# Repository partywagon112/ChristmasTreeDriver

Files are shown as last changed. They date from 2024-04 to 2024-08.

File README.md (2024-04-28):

# Christmas Tree Driver
This really should get renamed, but the idea is to create a Matter based H-Bridge driver for my Home Assistant to control my Christmas tree lights at the end of the year.

Very much an in-progress effort...

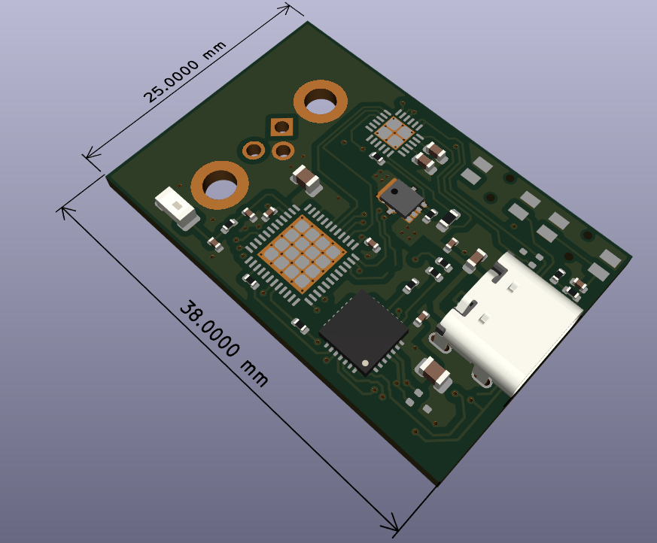
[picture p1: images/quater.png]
ThreeQuaterView


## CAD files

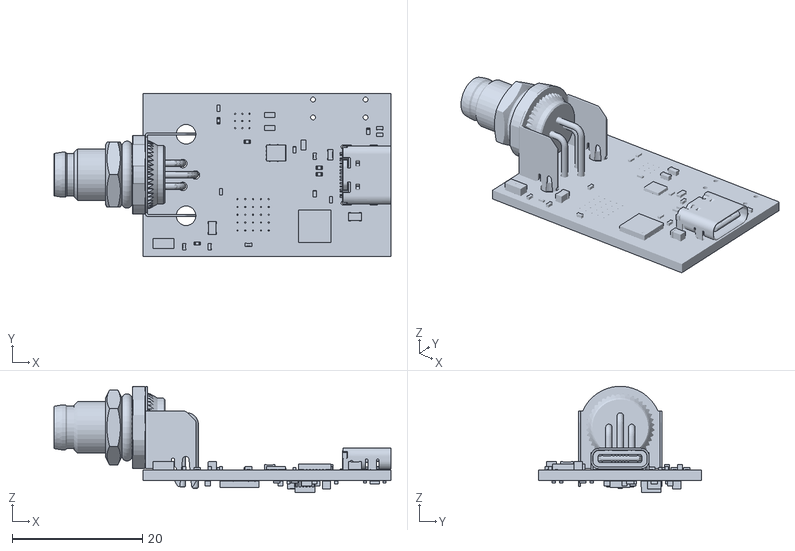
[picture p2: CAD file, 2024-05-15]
hardware/Unnamed-christmastreedriver 1.stl
51.7 x 25.0 x 16.3

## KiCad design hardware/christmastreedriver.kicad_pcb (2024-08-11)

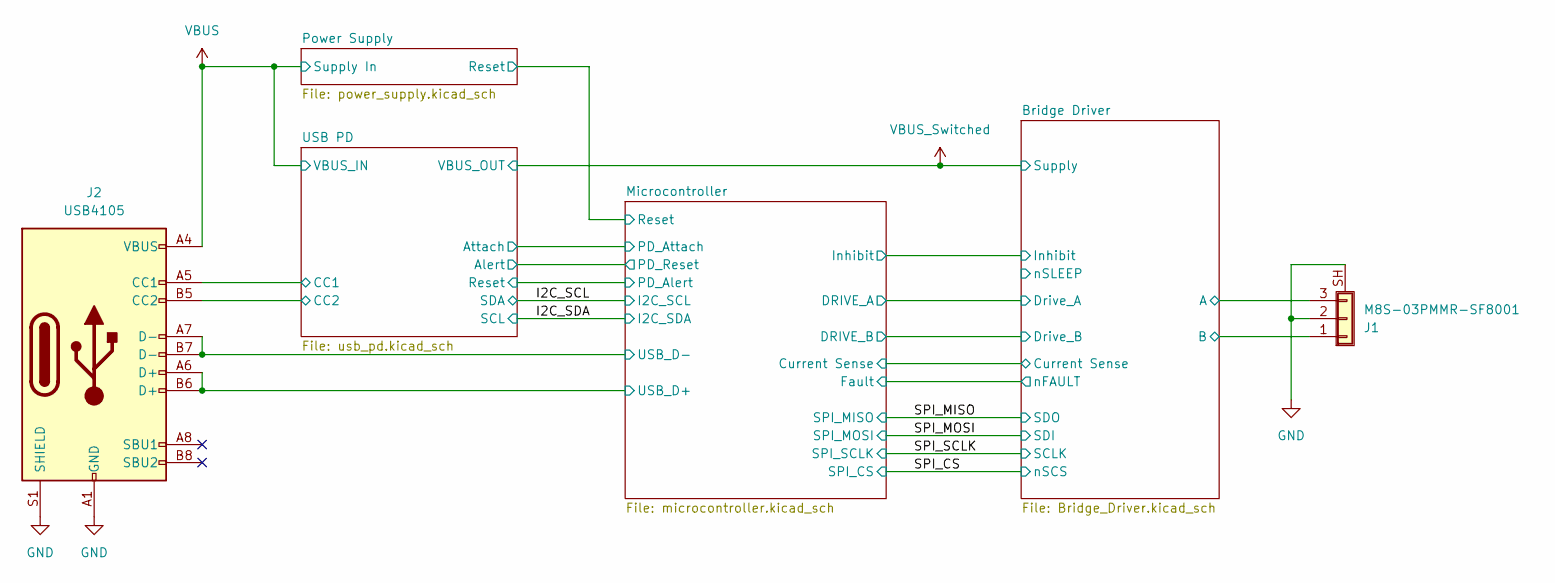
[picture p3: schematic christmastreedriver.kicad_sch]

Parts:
J1: M8S-03PMMR-SF8001; Amphenol_M8S-03PMMR-SF8001; MPN M8S-03PMMR-SF8001
J2: USB4105; USB_C_Receptacle_GCT_USB4105-xx-A_16P_TopMnt_Horizontal; MPN USB4105-GF-A

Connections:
/Bridge Driver/A: J1.3; also elsewhere on the board
/Bridge Driver/B: J1.1; also elsewhere on the board
/Microcontroller/USB_D+: J2.A6 (D+), J2.B6 (D+); also elsewhere on the board
/Microcontroller/USB_D-: J2.A7 (D-), J2.B7 (D-); also elsewhere on the board
/USB PD/CC1: J2.A5 (CC1); also elsewhere on the board
/USB PD/CC2: J2.B5 (CC2); also elsewhere on the board
GND: J1.2, J1.SH (Shield), J2.A1 (GND), J2.A12 (GND), J2.B1 (GND), J2.B12 (GND), J2.S1 (SHIELD); also elsewhere on the board
VBUS: J2.A4 (VBUS), J2.A9 (VBUS), J2.B4 (VBUS), J2.B9 (VBUS); also elsewhere on the board

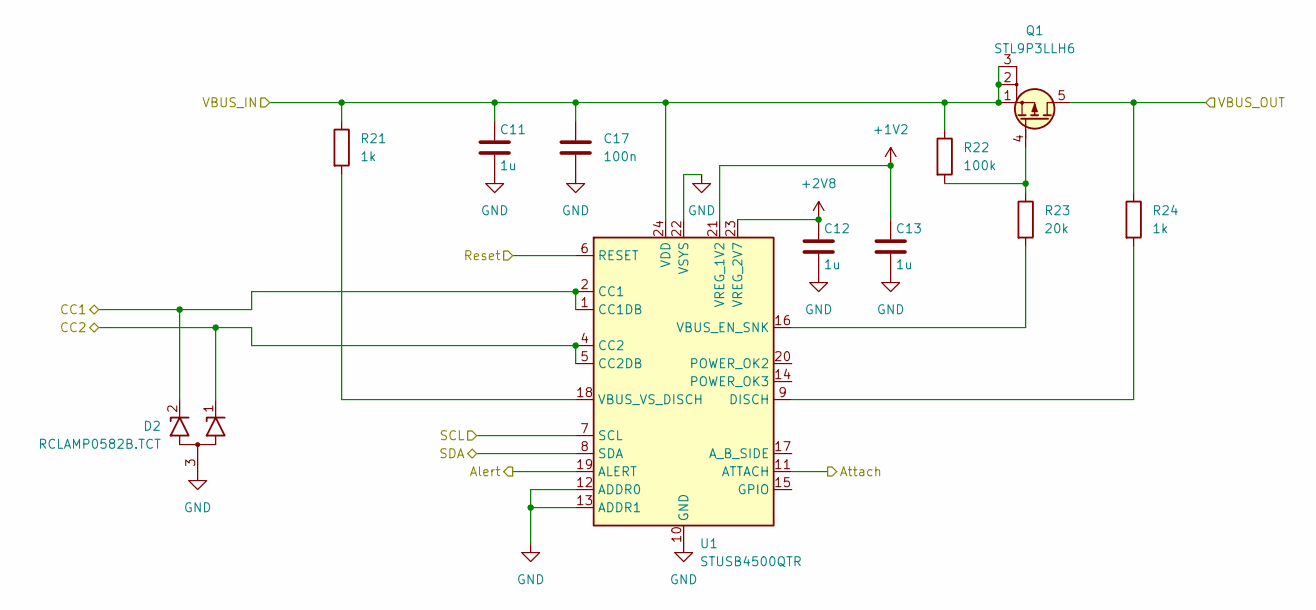
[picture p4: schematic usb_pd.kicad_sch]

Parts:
C11, C12, C13: 1u; C_0603_1608Metric; MPN GRT188R61H105KE13D
C17: 100n; C_0402_1005Metric; MPN GCM155R71H104KE02J
D2: RCLAMP0582B.TCT; SOT-416; MPN RCLAMP0582B.TCT
Q1: STL9P3LLH6; ST_PowerFlat-8; MPN STL9P3LLH6
R21, R24: 1k; R_0603_1608Metric; MPN CR0603AFX-1001ELF
R22: 100k; R_0402_1005Metric; MPN ERJ-2RKF1003X
R23: 20k; R_0402_1005Metric; MPN ERJ-2RKF2002X
U1: STUSB4500QTR; QFN-24-1EP_4x4mm_P0.5mm_EP2.7x2.7mm_ThermalVias; MPN STUSB4500QTR

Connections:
+1V2: C13.1, U1.21 (VREG_1V2)
+2V8: C12.1, U1.23 (VREG_2V7)
/I2C_SCL: U1.8 (SDA); also elsewhere on the board
/I2C_SDA: U1.7 (SCL); also elsewhere on the board
/Microcontroller/PD_Alert: U1.6 (RESET); also elsewhere on the board
/Microcontroller/PD_Attach: U1.11 (ATTACH); also elsewhere on the board
/Microcontroller/PD_Reset: U1.19 (ALERT); also elsewhere on the board
/USB PD/CC1: D2.2 (K2), U1.1 (CC1DB), U1.2 (CC1); also elsewhere on the board
/USB PD/CC2: D2.1 (K1), U1.4 (CC2), U1.5 (CC2DB); also elsewhere on the board
GND: C11.2, C12.2, C13.2, C17.2, D2.3 (A), U1.10 (GND), U1.12 (ADDR0), U1.13 (ADDR1), U1.22 (VSYS), U1.25 (GND); also elsewhere on the board
unnamed: Q1.4 (G), R22.2, R23.1
unnamed: R24.2, U1.9 (DISCH)
unnamed: R23.2, U1.16 (VBUS_EN_SNK)
unnamed: R21.2, U1.18 (VBUS_VS_DISCH)
VBUS: C11.1, C17.1, Q1.1 (S), Q1.2 (S), Q1.3 (S), R21.1, R22.1, U1.24 (VDD); also elsewhere on the board
VBUS_Switched: Q1.5 (D), R24.1; also elsewhere on the board

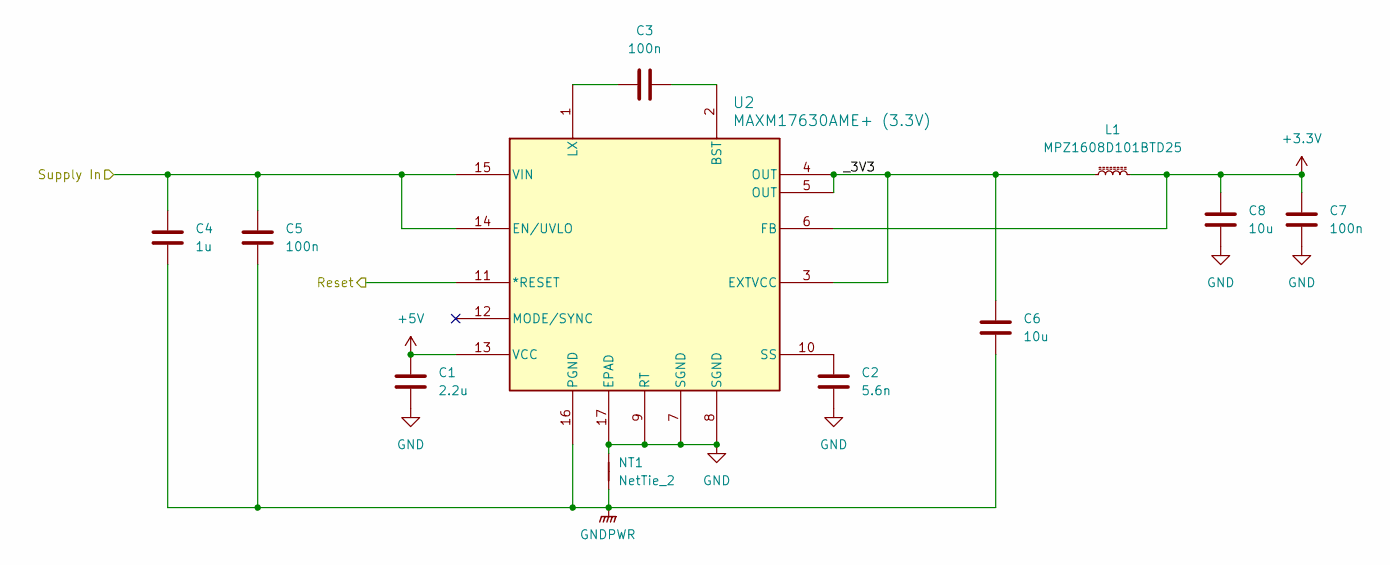
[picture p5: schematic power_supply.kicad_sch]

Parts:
C1: 2.2u; C_0603_1608Metric; MPN GRT188R61H225KE13D
C2: 5.6n; C_0402_1005Metric; MPN GCM155R71H562KA55D
C3, C5, C7: 100n; C_0402_1005Metric; MPN GCM155R71H104KE02J
C4: 1u; C_0603_1608Metric; MPN GRT188R61H105KE13D
C6, C8: 10u; C_0805_2012Metric; MPN GCM21BR70J106KE22L
L1: MPZ1608D101BTD25; L_0603_1608Metric; MPN MPZ1608D101BTD25
NT1: NetTie_2; NetTie-2_SMD_Pad0.5mm
U2: MAXM17630AME+ (3.3V); 16-eMGA (3x3); MPN MAXM17630AME+T

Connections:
+3.3V: C7.1, C8.1, L1.2, U2.6 (FB); also elsewhere on the board
+5V: C1.1, U2.13 (VCC); also elsewhere on the board
/Microcontroller/Reset: U2.11 (*RESET); also elsewhere on the board
/Power Supply/_3V3: C6.1, L1.1, U2.3 (EXTVCC), U2.4 (OUT), U2.5 (OUT)
GND: C1.2, C2.2, C7.2, C8.2, NT1.2, U2.7 (SGND), U2.8 (SGND), U2.9 (RT), U2.17 (EPAD); also elsewhere on the board
GNDPWR: C4.2, C5.2, C6.2, NT1.1, U2.16 (PGND)
unnamed: C3.2, U2.2 (BST)
unnamed: C3.1, U2.1 (LX)
unnamed: C2.1, U2.10 (SS)
VBUS: C4.1, C5.1, U2.14 (EN/UVLO), U2.15 (VIN); also elsewhere on the board

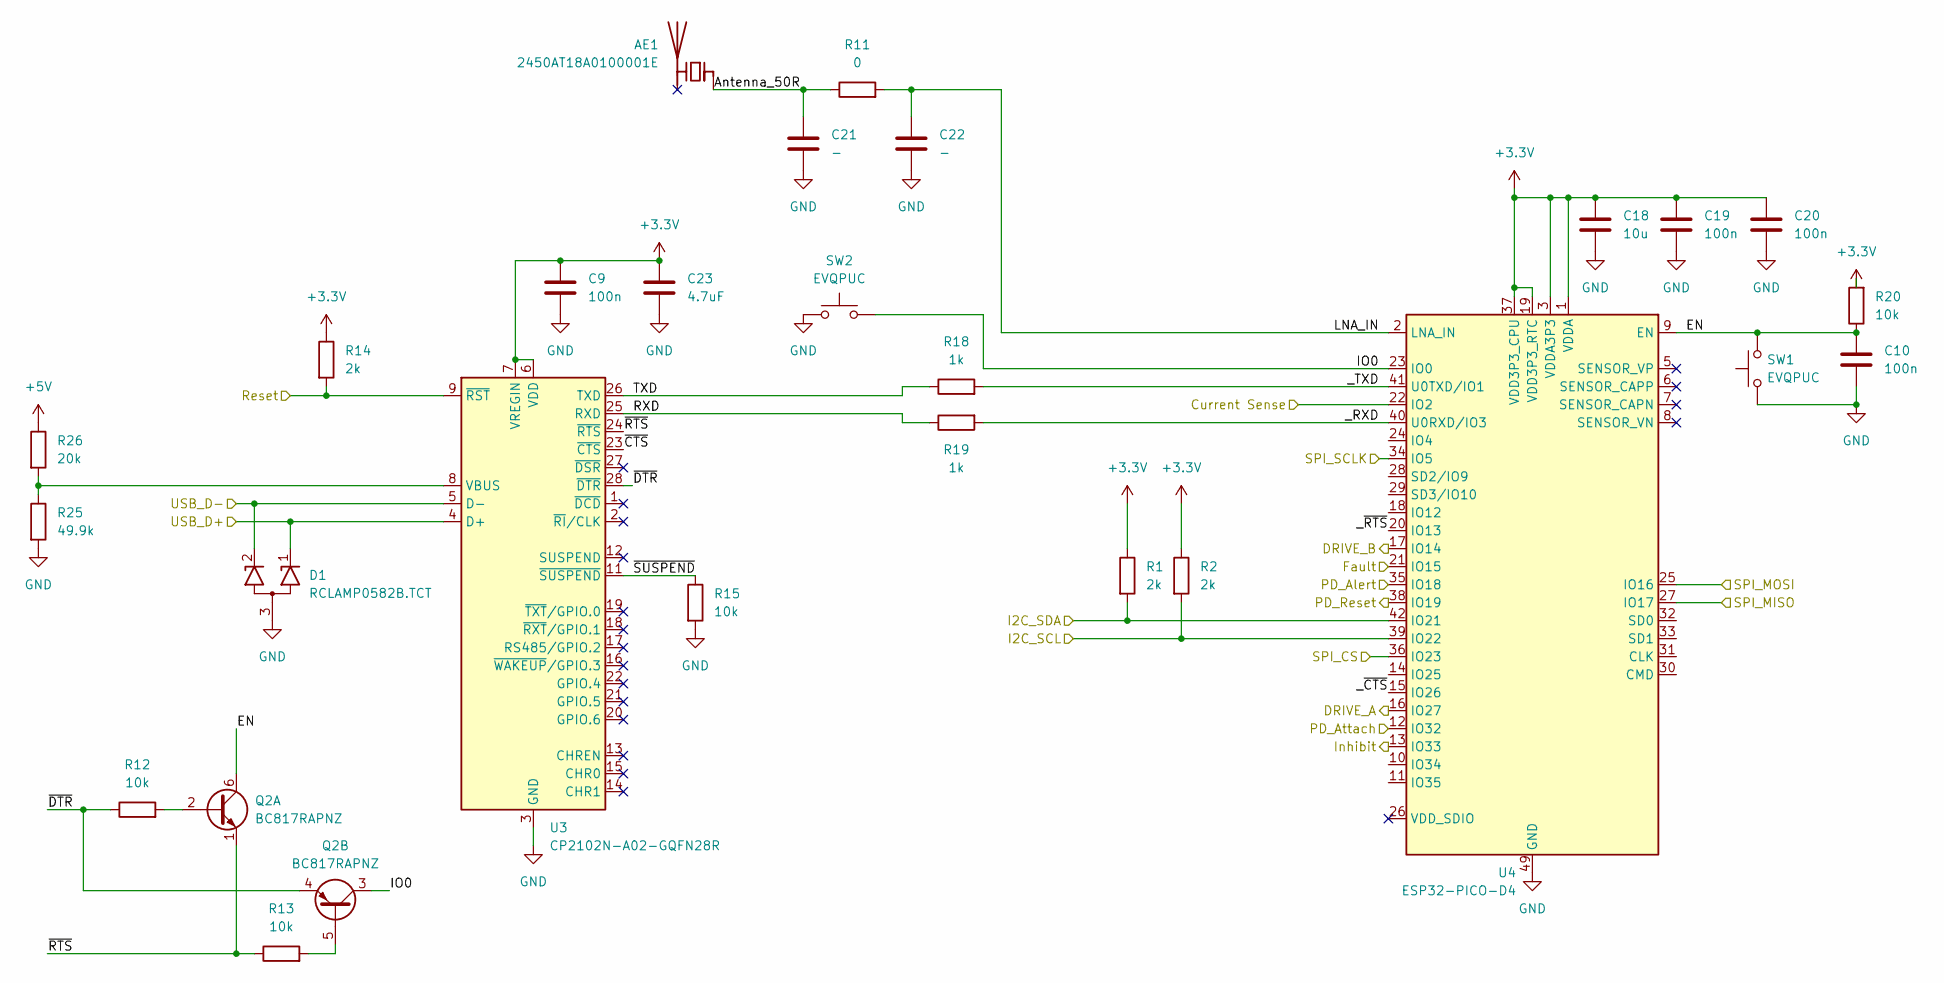
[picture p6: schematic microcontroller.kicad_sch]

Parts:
AE1: 2450AT18A0100001E; Johanson_2450AT18x100; MPN 2450AT18A0100001E
C9, C10, C19, C20: 100n; C_0402_1005Metric; MPN GCM155R71H104KE02J
C18: 10u; C_0805_2012Metric; MPN GCM21BR70J106KE22L
C21, C22: -; C_0402_1005Metric; Part-DB Footprint 0402
C23: 4.7uF; C_0805_2012Metric; MPN GCM21BC71A475KA73L
D1: RCLAMP0582B.TCT; SOT-416; MPN RCLAMP0582B.TCT
Q2: BC817RAPNZ; DFN1412-6; MPN BC817RAPNZ
R1, R2, R14: 2k; R_0402_1005Metric; MPN CR0402AFX-2001GAS
R11: 0; R_0402_1005Metric; MPN CR0402AJ/-000GLF
R12, R13, R15, R20: 10k; R_0402_1005Metric; MPN CR0402AFX-1002GAS
R18, R19: 1k; R_0402_1005Metric; MPN CR0402AFX-1001GAS
R25: 49.9k; R_0402_1005Metric; MPN CR0402AFX-4992GAS
R26: 20k; R_0402_1005Metric; MPN ERJ-2RKF2002X
SW1, SW2: EVQPUC; Panasonic_EVQPUL_EVQPUC; MPN EVQ-PUC02K
U3: CP2102N-A02-GQFN28R; QFN-28-1EP_5x5mm_P0.5mm_EP3.35x3.35mm_ThermalVias; MPN CP2102N-A02-GQFN28R
U4: ESP32-PICO-D4; QFN-48-1EP_7x7mm_P0.5mm_EP5.3x5.3mm_ThermalVias; MPN ESP32-PICO-D4

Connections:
+3.3V: C9.1, C18.1, C19.1, C20.1, C23.1, R1.1, R2.1, R14.1, R20.2, U3.6 (VDD), U3.7 (VREGIN), U4.1 (VDDA), U4.3 (VDDA3P3), U4.4 (VDDA3P3), U4.19 (VDD3P3_RTC), U4.37 (VDD3P3_CPU), U4.43 (VDDA), U4.46 (VDDA); also elsewhere on the board
+5V: R26.1; also elsewhere on the board
/Bridge Driver/Current Sense: U4.22 (IO2); also elsewhere on the board
/Bridge Driver/_DRVOFF: U4.13 (IO33); also elsewhere on the board
/Bridge Driver/_EN/IN1: U4.16 (IO27); also elsewhere on the board
/Bridge Driver/_PH/IN2: U4.17 (IO14); also elsewhere on the board
/Bridge Driver/nFAULT: U4.21 (IO15); also elsewhere on the board
/I2C_SCL: R2.2, U4.39 (IO22); also elsewhere on the board
/I2C_SDA: R1.2, U4.42 (IO21); also elsewhere on the board
/Microcontroller/Antenna_50R: AE1.1 (FEED), C21.1, R11.1
/Microcontroller/EN: C10.1, Q2.6 (C1), R20.1, SW1.2, U4.9 (EN)
/Microcontroller/IO0: Q2.3 (C2), SW2.2, U4.23 (IO0)
/Microcontroller/LNA_IN: C22.1, R11.2, U4.2 (LNA_IN)
/Microcontroller/PD_Alert: U4.35 (IO18); also elsewhere on the board
/Microcontroller/PD_Attach: U4.12 (IO32); also elsewhere on the board
/Microcontroller/PD_Reset: U4.38 (IO19); also elsewhere on the board
/Microcontroller/RXD: R19.1, U3.25 (RXD)
/Microcontroller/Reset: R14.2, U3.9 (~RST); also elsewhere on the board
/Microcontroller/TXD: R18.1, U3.26 (TXD)
/Microcontroller/USB_D+: D1.1 (K1), U3.4 (D+); also elsewhere on the board
/Microcontroller/USB_D-: D1.2 (K2), U3.5 (D-); also elsewhere on the board
/Microcontroller/_RXD: R19.2, U4.40 (U0RXD/IO3)
/Microcontroller/_TXD: R18.2, U4.41 (U0TXD/IO1)
/Microcontroller/_~CTS: U4.15 (IO26)
/Microcontroller/_~RTS: U4.20 (IO13)
/Microcontroller/~CTS: U3.23 (~CTS)
/Microcontroller/~DTR: Q2.4 (E2), R12.1, U3.28 (~DTR)
/Microcontroller/~RTS: Q2.1 (E1), R13.1, U3.24 (~RTS)
/Microcontroller/~SUSPEND: R15.1, U3.11 (~SUSPEND)
/SPI_CS: U4.36 (IO23); also elsewhere on the board
/SPI_MISO: U4.27 (IO17); also elsewhere on the board
/SPI_MOSI: U4.25 (IO16); also elsewhere on the board
/SPI_SCLK: U4.34 (IO5); also elsewhere on the board
GND: AE1.2 (PCB_Trace), C9.2, C10.2, C18.2, C19.2, C20.2, C21.2, C22.2, C23.2, D1.3 (A), R15.2, R25.2, SW1.1, SW2.1, U3.3 (GND), U3.29 (GND), U4.49 (GND); also elsewhere on the board
unnamed: Q2.2 (B1), R12.2
unnamed: Q2.5 (B2), R13.2
unnamed: R25.1, R26.2, U3.8 (VBUS)

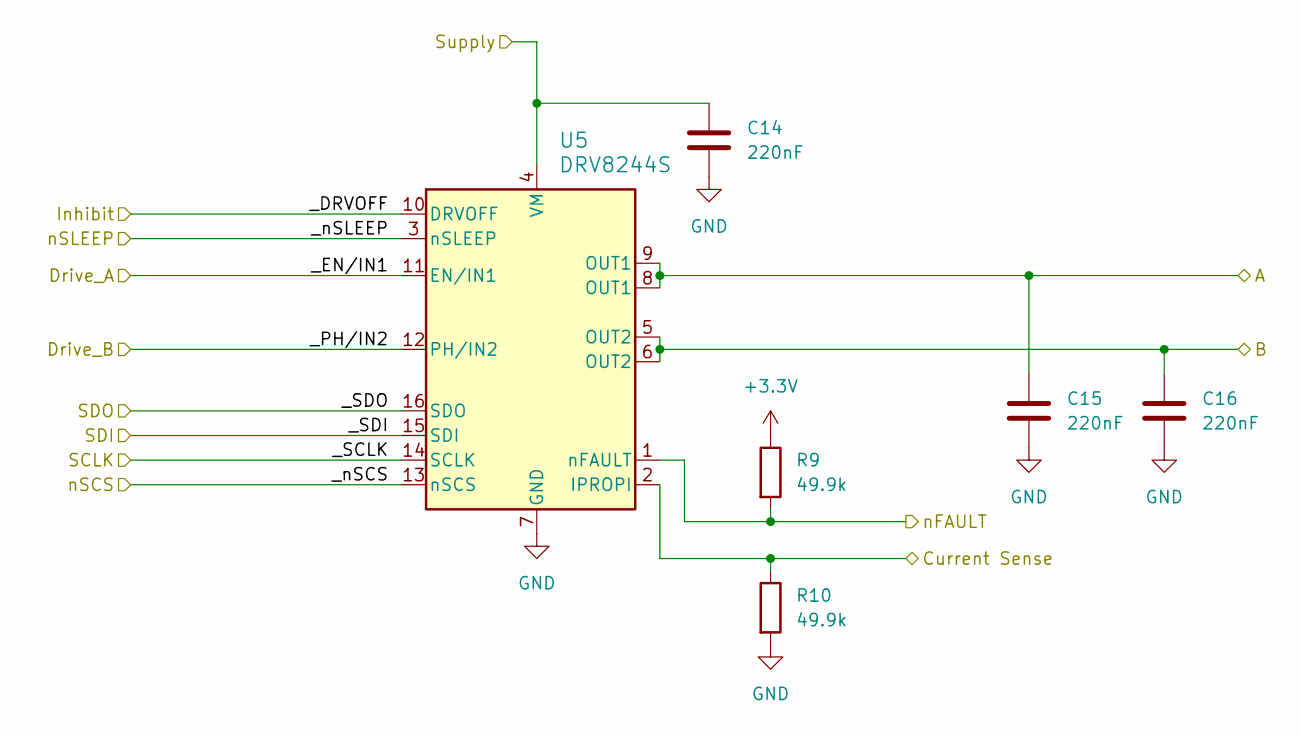
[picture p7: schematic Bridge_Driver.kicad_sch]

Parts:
C14, C15, C16: 220nF; C_0603_1608Metric; MPN GCM188R71H224KA64D
R9, R10: 49.9k; R_0402_1005Metric; MPN CR0402AFX-4992GAS
U5: DRV8244S; VQFN-16_RYJ_TEX; MPN DRV8244SQRYJRQ1

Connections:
+3.3V: R9.1; also elsewhere on the board
/Bridge Driver/A: C15.1, U5.8 (OUT1), U5.9 (OUT1); also elsewhere on the board
/Bridge Driver/B: C16.1, U5.5 (OUT2), U5.6 (OUT2); also elsewhere on the board
/Bridge Driver/Current Sense: R10.1, U5.2 (IPROPI); also elsewhere on the board
/Bridge Driver/_DRVOFF: U5.10 (DRVOFF); also elsewhere on the board
/Bridge Driver/_EN/IN1: U5.11 (EN/IN1); also elsewhere on the board
/Bridge Driver/_PH/IN2: U5.12 (PH/IN2); also elsewhere on the board
/Bridge Driver/_nSLEEP: U5.3 (nSLEEP)
/Bridge Driver/nFAULT: R9.2, U5.1 (nFAULT); also elsewhere on the board
/SPI_CS: U5.13 (nSCS); also elsewhere on the board
/SPI_MISO: U5.16 (SDO); also elsewhere on the board
/SPI_MOSI: U5.15 (SDI); also elsewhere on the board
/SPI_SCLK: U5.14 (SCLK); also elsewhere on the board
GND: C14.2, C15.2, C16.2, R10.2, U5.7 (GND); also elsewhere on the board
VBUS_Switched: C14.1, U5.4 (VM); also elsewhere on the board

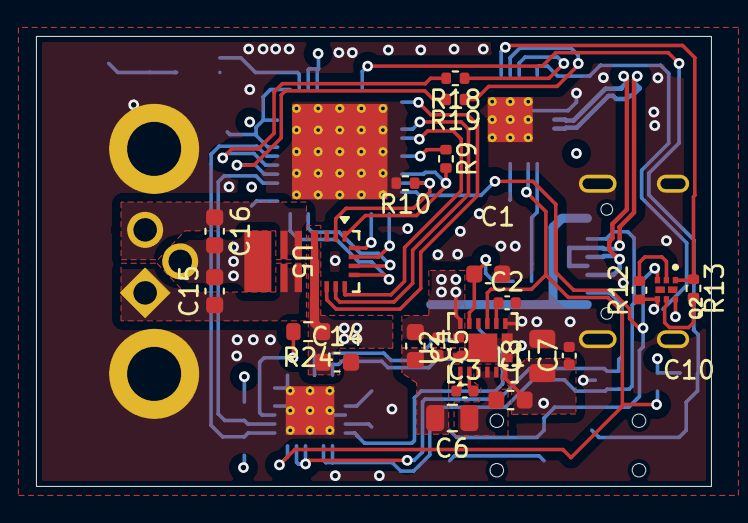
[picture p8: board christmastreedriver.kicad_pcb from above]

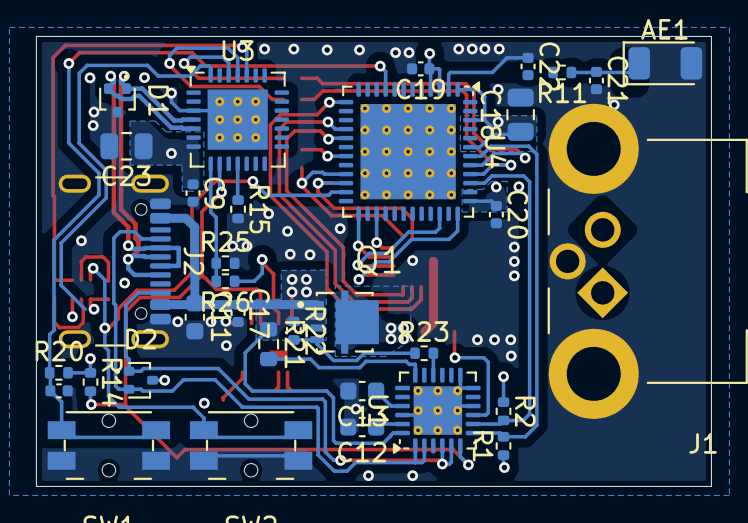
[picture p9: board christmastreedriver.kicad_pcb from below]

Board: 4 copper layers, 37.5 x 25.0 mm, 57 parts (34 on the bottom side), 51 nets.

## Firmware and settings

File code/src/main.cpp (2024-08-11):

#include "Arduino.h"
#include "Matter.h"
#include <app/server/OnboardingCodesUtil.h>
#include <credentials/examples/DeviceAttestationCredsExample.h>
#include "Pinout.h"
using namespace chip;
using namespace chip::app::Clusters;
using namespace esp_matter;
using namespace esp_matter::endpoint;

/**
 * This program presents example Matter light device with OnOff cluster by
 * controlling LED with Matter and toggle button.
 *
 * If your ESP does not have buildin LED, please connect it to LED_PIN
 *
 * You can toggle light by both:
 *  - Matter (via CHIPTool or other Matter controller)
 *  - toggle button (by default attached to GPIO0 - reset button, with debouncing) 
 */

// Debounce for toggle button
const int DEBOUNCE_DELAY = 500;
int last_toggle;

// Cluster and attribute ID used by Matter light device
const uint32_t CLUSTER_ID = OnOff::Id;
const uint32_t ATTRIBUTE_ID = OnOff::Attributes::OnOff::Id;

// Endpoint and attribute ref that will be assigned to Matter device
uint16_t light_endpoint_id = 0;
attribute_t *attribute_ref;

// There is possibility to listen for various device events, related for example to setup process
// Leaved as empty for simplicity
static void on_device_event(const ChipDeviceEvent *event, intptr_t arg) {}
static esp_err_t on_identification(identification::callback_type_t type, uint16_t endpoint_id,
                                   uint8_t effect_id, uint8_t effect_variant, void *priv_data) {
  return ESP_OK;
}

// Listener on attribute update requests.
// In this example, when update is requested, path (endpoint, cluster and attribute) is checked
// if it matches light attribute. If yes, LED changes state to new one.
static esp_err_t on_attribute_update(attribute::callback_type_t type, uint16_t endpoint_id, uint32_t cluster_id,
                                     uint32_t attribute_id, esp_matter_attr_val_t *val, void *priv_data) {
  if (type == attribute::PRE_UPDATE && endpoint_id == light_endpoint_id &&
      cluster_id == CLUSTER_ID && attribute_id == ATTRIBUTE_ID) {
    // We got an light on/off attribute update!
    bool new_state = val->val.b;
    digitalWrite(LED_PIN, new_state);
  }
  return ESP_OK;
}

void setup() {
  Serial.begin(115200);
  pinMode(LED_PIN, OUTPUT);
  pinMode(TOGGLE_BUTTON_PIN, INPUT);

  // Enable debug logging
  esp_log_level_set("*", ESP_LOG_DEBUG);

  // Setup Matter node
  node::config_t node_config;
  node_t *node = node::create(&node_config, on_attribute_update, on_identification);

  // Setup Light endpoint / cluster / attributes with default values
  on_off_light::config_t light_config;
  light_config.on_off.on_off = false;
  light_config.on_off.lighting.start_up_on_off = false;
  endpoint_t *endpoint = on_off_light::create(node, &light_config, ENDPOINT_FLAG_NONE, NULL);

  // Save on/off attribute reference. It will be used to read attribute value later.
  attribute_ref = attribute::get(cluster::get(endpoint, CLUSTER_ID), ATTRIBUTE_ID);

  // Save generated endpoint id
  light_endpoint_id = endpoint::get_id(endpoint);
  
  // Setup DAC (this is good place to also set custom commission data, passcodes etc.)
  esp_matter::set_custom_dac_provider(chip::Credentials::Examples::GetExampleDACProvider());

  // Start Matter device
  esp_matter::start(on_device_event);

  // Print codes needed to setup Matter device
  PrintOnboardingCodes(chip::RendezvousInformationFlags(chip::RendezvousInformationFlag::kBLE));
}

// Reads light on/off attribute value
esp_matter_attr_val_t get_onoff_attribute_value() {
  esp_matter_attr_val_t onoff_value = esp_matter_invalid(NULL);
  attribute::get_val(attribute_ref, &onoff_value);
  return onoff_value;
}

// Sets light on/off attribute value
void set_onoff_attribute_value(esp_matter_attr_val_t* onoff_value) {
  attribute::update(light_endpoint_id, CLUSTER_ID, ATTRIBUTE_ID, onoff_value);
}

// When toggle light button is pressed (with debouncing),
// light attribute value is changed
void loop() {
  if ((millis() - last_toggle) > DEBOUNCE_DELAY) {
    if (!digitalRead(TOGGLE_BUTTON_PIN)) {
      last_toggle = millis();
      // Read actual on/off value, invert it and set
      esp_matter_attr_val_t onoff_value = get_onoff_attribute_value();
      onoff_value.val.b = !onoff_value.val.b;
      set_onoff_attribute_value(&onoff_value);
    }
  }
}

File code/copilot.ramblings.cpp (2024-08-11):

#include <Wire.h>
#include <SPI.h>

// Define SPI pins
const int SPI_MISO = 17; // MISO (Master In Slave Out)
const int SPI_MOSI = 16; // MOSI (Master Out Slave In)
const int SPI_SCK = 5;   // SCK (Serial Clock)
const int SPI_CS = 23;   // CS (Chip Select)

// Define I2C pins
const int I2C_SDA = 21; // SDA (Serial Data)
const int I2C_SCL = 22; // SCL (Serial Clock)

void setup() {
  // Initialize SPI
  SPI.begin();
  // SPI.beginTransaction(SPISettings(1000000, MSBFIRST, SPI_MODE0));
  pinMode(SPI_CS, OUTPUT);

  // Initialize I2C
  Wire.begin(I2C_SDA, I2C_SCL);

  // Other setup code
}

void loop() {
  // Your SPI and I2C communication code here
}

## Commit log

2024-05-15 Generated first bom
    [Bridge_Driver.kicad_sch, Unnamed-christmastreedriver 1.stl, christmastreedriver.kicad_pcb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]
2024-08-11 Flipped some stuff
    [christmastreedriver.kicad_pcb, christmastreedriver.kicad_sch, microcontroller.kicad_sch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]
